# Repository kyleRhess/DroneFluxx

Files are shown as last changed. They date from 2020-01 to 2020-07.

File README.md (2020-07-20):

# DroneFluxx

## A custom quadcopter flight controller


### Firmware

The current firmware version is tailored for an STM32F4 microcontroller. This means that it is best-suited for the related hardware, and much of this firmware is very proprietary.
\
However, the lightweight [`PID module`](https://github.com/kyleRhess/DroneFluxx/blob/master/src/PID.c) built for this project could be useful in other applications.

### Hardware

Flight controller hardware is still in work, [`but has been made public`](https://github.com/kyleRhess/DroneFluxx/tree/master/Hardware) for those who are interested.

Alternate text

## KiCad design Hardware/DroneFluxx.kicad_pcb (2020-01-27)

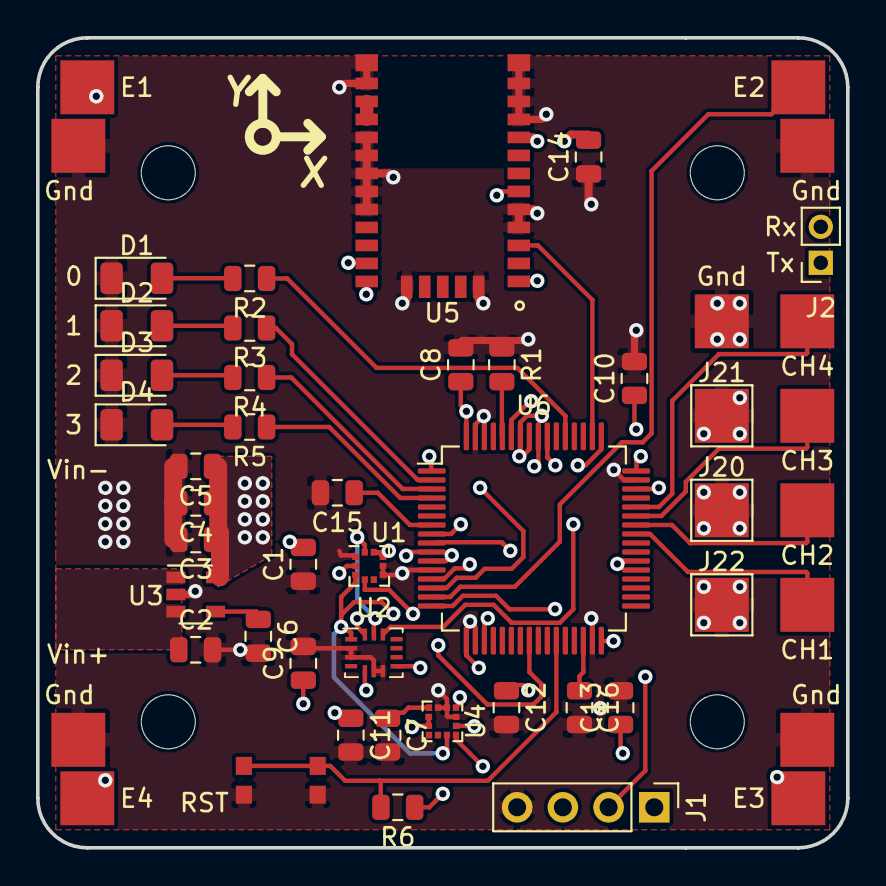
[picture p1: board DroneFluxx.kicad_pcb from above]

Board: 4 copper layers, 45.0 x 45.0 mm, 51 parts (0 on the bottom side), 40 nets.

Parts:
C1, C4, C7, C8, C10, C11, C12, C13, C15: 0.1uF; C_0805_2012Metric
C2, C9: 1uF; C_0805_2012Metric
C3, C16: 2.2uF; C_0805_2012Metric
C5, C6: 10nF; C_0805_2012Metric
C14: 4.7uF; C_0805_2012Metric
CH1, CH2, CH3, CH4: Conn_01x01_Female; Measurement_Point_Square-SMD-Pad_Big
D1, D2, D3, D4: LED; LED_1206_3216Metric
E1, E2, E3, E4: Conn_01x01_Female; Measurement_Point_Square-SMD-Pad_Big
Gnd: Conn_01x01_Female; Measurement_Point_Square-SMD-Pad_Big
Gnd#2, Gnd#3, Gnd#4, Gnd#5: Conn_01x01_Female; Measurement_Point_Square-SMD-Pad_Big
J1: Conn_01x04_Male; PinHeader_1x04_P2.54mm_Vertical
J2: Conn_01x02_Female; PinSocket_1x02_P2.00mm_Vertical
J20, J21, J22: Conn_01x01_Female; TestPoint_Pad_3.0x3.0mm
R1, R6: 10k; R_0805_2012Metric
R2, R3, R4, R5: 470; R_0805_2012Metric
RST: SW_Push; SW_SPST_KMR2
U1: BMP388; LGA-10_2x2mm_Pitch0.5mm
U2: LSM6DSM; Bosch_LGA-14_3x2.5mm_P0.5mm
U3: LP2985-3.3; SOT-23-5
U4: LIS3MDL; LGA-12_2x2mm_P0.5mm
U5: CAM-M8C-0; 31-SMD_Module
U6: STM32F410RBTx; LQFP-64_10x10mm_P0.5mm

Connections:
+3V3: C1.2, C3.1, C4.1, C5.1, C8.1, C9.1, C10.1, C11.1, C12.1, C13.1, C14.2, J1.3, R6.1, U1.1, U1.10, U2.5, U2.8, U3.5, U4.5, U4.6, U5.1, U5.9, U6.1, U6.13, U6.19, U6.32, U6.48, U6.64
+12V: C2.1, U3.1, U3.3
ESC1: E1.1, U6.14
ESC2: E2.1, U6.15
ESC3: E3.1, U6.16
ESC4: E4.1, U6.17
GND: C1.1, C2.2, C3.2, C4.2, C5.2, C6.2, C7.2, C8.2, C9.2, C10.2, C11.2, C12.2, C13.2, C14.1, C15.2, C16.2, D1.1, D2.1, D3.1, D4.1, Gnd.1, Gnd#2.1, Gnd#3.1, Gnd#4.1, Gnd#5.1, J1.4, J20.1, J21.1, J22.1, R1.1, RST.2, U1.3, U1.8, U1.9, U2.2, U2.3, U2.6, U2.7, U3.2, U4.2, U4.3, U4.12, U5.4, U5.5, U5.10, U5.11, U5.12, U5.13, U5.14, U5.15, U5.18, U5.19, U5.20, U5.21, U5.22, U5.27, U5.31, U6.12, U6.18, U6.31, U6.47, U6.63
LED_A: R2.1, U6.53
LED_B: R3.1, U6.2
LED_C: R4.1, U6.3
LED_D: R5.1, U6.4
unnamed: C6.1, U3.4
unnamed: C7.1, U4.4
unnamed: C15.1, U6.7
unnamed: C16.1, U6.30
unnamed: D1.2, R2.2
unnamed: D2.2, R3.2
unnamed: D3.2, R4.2
unnamed: D4.2, R5.2
unnamed: R1.2, U6.60
unnamed: U5.16, U5.17
RST_SW: R6.2, RST.1, U6.27
Rx_CH1: CH1.1, U6.41
Rx_CH2: CH2.1, U6.42
Rx_CH3: CH3.1, U6.43
Rx_CH4: CH4.1, U6.44
SPI1_CLK: U5.6, U6.55
SPI1_CS0: U5.3, U6.50
SPI1_MISO: U5.25, U6.56
SPI1_MOSI: U5.26, U6.57
SPI2_CLK: U1.2, U2.13, U4.1, U6.38
SPI2_CS0: U2.12, U6.8
SPI2_CS1: U4.10, U6.9
SPI2_CS2: U1.6, U6.24
SPI2_MISO: U1.5, U2.1, U4.9, U6.10
SPI2_MOSI: U1.4, U2.14, U4.11, U6.11
SWCLK: J1.2, U6.49
SWDIO: J1.1, U6.46
USART1_RX: J2.2, U6.59
USART1_TX: J2.1, U6.58

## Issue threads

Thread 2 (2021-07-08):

PID Windup Logic Bug

kyleRhess, 2021-07-08:
The integrator windup method in the PID library is incorrect and should be revisited.

Closed 2021-07-08.

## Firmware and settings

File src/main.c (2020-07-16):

/*
 * This file is part of the µOS++ distribution.
 *   (https://github.com/micro-os-plus)
 * Copyright (c) 2014 Liviu Ionescu.
 *
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
 * THE SOFTWARE IS PROVIDED "AS IS", WITHOUT WARRANTY OF ANY KIND,
 * EXPRESS OR IMPLIED, INCLUDING BUT NOT LIMITED TO THE WARRANTIES
 * OF MERCHANTABILITY, FITNESS FOR A PARTICULAR PURPOSE AND
 * NONINFRINGEMENT. IN NO EVENT SHALL THE AUTHORS OR COPYRIGHT
 * HOLDERS BE LIABLE FOR ANY CLAIM, DAMAGES OR OTHER LIABILITY,
 * WHETHER IN AN ACTION OF CONTRACT, TORT OR OTHERWISE, ARISING
 * FROM, OUT OF OR IN CONNECTION WITH THE SOFTWARE OR THE USE OR
 * OTHER DEALINGS IN THE SOFTWARE.
 */

/*
 *
____________________  _____________________________________  _________
___  ____/_  __ \_  |/ /__  ____/__  /____  _/_  ____/__  / / /__  __/
__  /_   _  / / /_    /__  /_   __  /  __  / _  / __ __  /_/ /__  /
_  __/   / /_/ /_    | _  __/   _  /____/ /  / /_/ / _  __  / _  /
/_/      \____/ /_/|_| /_/      /_____/___/  \____/  /_/ /_/  /_/
 *
 */

// ----------------------------------------------------------------------------
#include <stdio.h>
#include <stdlib.h>
#include <string.h>
#include <math.h>
#include "diag/Trace.h"
#include "cmsis_device.h"
#include "stm32f4xx.h"
#include "stm32f4xx_hal.h"
#include "stm32f4xx_hal_tim.h"
#include "System.h"

#define SQR(xxx) 			((xxx) * (xxx))

// ----------------------------------------------------------------------------
//
// Semihosting STM32F4 empty sample (trace via DEBUG).
//
// Trace support is enabled by adding the TRACE macro definition.
// By default the trace messages are forwarded to the DEBUG output,
// but can be rerouted to any device or completely suppressed, by
// changing the definitions required in system/src/diag/trace_impl.c
// (currently OS_USE_TRACE_ITM, OS_USE_TRACE_SEMIHOSTING_DEBUG/_STDOUT).
//

// ----- main() ---------------------------------------------------------------

// Sample pragmas to cope with warnings. Please note the related line at
// the end of this function, used to pop the compiler diagnostics status.
#pragma GCC diagnostic push
#pragma GCC diagnostic ignored "-Wunused-parameter"
#pragma GCC diagnostic ignored "-Wmissing-declarations"
#pragma GCC diagnostic ignored "-Wreturn-type"

static void setHighSystemClk(void);

int main(int argc, char* argv[])
{
	int status = HAL_OK;

	setHighSystemClk();
	status = InitializeSystem();

	RCC->AHB1ENR = RCC_AHB1ENR_GPIOCEN;
	RCC->AHB1ENR |= RCC_AHB1ENR_GPIOAEN;

	__HAL_RCC_GPIOB_CLK_ENABLE();

	GPIO_InitTypeDef gDataPin;
	gDataPin.Pin = GPIO_PIN_12 | GPIO_PIN_13 | GPIO_PIN_14 | GPIO_PIN_15;
	gDataPin.Mode = GPIO_MODE_OUTPUT_PP;
	gDataPin.Pull = GPIO_PULLUP;
	gDataPin.Speed = GPIO_SPEED_HIGH;
	HAL_GPIO_Init(GPIOC, &gDataPin);

	// Catch initialize failure
	while(status)
	{
		if(status & ERROR_IMU) 	aircraft_WriteLED(LED_A, 1);
		if(status & ERROR_BARO) aircraft_WriteLED(LED_B, 1);
		if(status & ERROR_GPS) 	aircraft_WriteLED(LED_C, 1);
		if(status & ERROR_MAG) 	aircraft_WriteLED(LED_D, 1);
	}

	SYSTEM_STATE = SYS_STATE_IDLE;
	AIRCRAFT_STATE = AIRCRAFT_STATE_ALIGNING;

	while (1)
	{
		// Start main loop
		RunSystem();
		RunSerial();
	}
	return 0;
}

/*
 * Need to re-initialize clocks to use HSI for PLL and
 * use PLL as the system clock with proper configs.
 *
 * This does not get set properly initially since after reset
 * needs to use HSI as system clock
 */
void setHighSystemClk(void)
{
	RCC_OscInitTypeDef RCC_OscInitStruct;

	// Use HSI and activate PLL with HSI as source.
	// This is tuned for NUCLEO-F411; update it for your board.
	RCC_OscInitStruct.OscillatorType = RCC_OSCILLATORTYPE_HSI;
	RCC_OscInitStruct.HSIState = RCC_HSI_ON;

	// 16 is the average calibration value, adjust for your own board.
	RCC_OscInitStruct.HSICalibrationValue = 16;
	RCC_OscInitStruct.PLL.PLLSource = RCC_PLLSOURCE_HSI;

	// This assumes the HSI_VALUE is a multiple of 1 MHz. If this is not
	// your case, you have to recompute these PLL constants.
	RCC_OscInitStruct.PLL.PLLM = (HSI_VALUE/1000000u);
	RCC_OscInitStruct.PLL.PLLN = 400; // for 100 MHz
	RCC_OscInitStruct.PLL.PLLP = RCC_PLLP_DIV4; /* 84 MHz, conservative */
	RCC_OscInitStruct.PLL.PLLQ = 7; /* To make USB work. */
	RCC_OscInitStruct.PLL.PLLState = RCC_PLL_ON;
	HAL_RCC_OscConfig(&RCC_OscInitStruct);

	RCC_ClkInitTypeDef RCC_ClkInitStruct;

	// Select PLL as system clock source and configure the HCLK, PCLK1 and PCLK2
	// clocks dividers
	RCC_ClkInitStruct.ClockType = (RCC_CLOCKTYPE_SYSCLK | RCC_CLOCKTYPE_HCLK
	  | RCC_CLOCKTYPE_PCLK1 | RCC_CLOCKTYPE_PCLK2);
	RCC_ClkInitStruct.SYSCLKSource = RCC_SYSCLKSOURCE_PLLCLK;

	// This is expected to work for most large cores.
	// Check and update it for your own configuration.
	RCC_ClkInitStruct.AHBCLKDivider = RCC_SYSCLK_DIV1;
	RCC_ClkInitStruct.APB1CLKDivider = RCC_HCLK_DIV1;
	RCC_ClkInitStruct.APB2CLKDivider = RCC_HCLK_DIV1;
	HAL_RCC_ClockConfig(&RCC_ClkInitStruct, FLASH_LATENCY_5);

	HAL_SYSTICK_Config(HAL_RCC_GetHCLKFreq()/1000);

	HAL_SYSTICK_CLKSourceConfig(SYSTICK_CLKSOURCE_HCLK);
}


#pragma GCC diagnostic pop

// ----------------------------------------------------------------------------

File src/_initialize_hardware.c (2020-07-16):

/*
 * This file is part of the µOS++ distribution.
 *   (https://github.com/micro-os-plus)
 * Copyright (c) 2014 Liviu Ionescu.
 *
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
 * THE SOFTWARE IS PROVIDED "AS IS", WITHOUT WARRANTY OF ANY KIND,
 * EXPRESS OR IMPLIED, INCLUDING BUT NOT LIMITED TO THE WARRANTIES
 * OF MERCHANTABILITY, FITNESS FOR A PARTICULAR PURPOSE AND
 * NONINFRINGEMENT. IN NO EVENT SHALL THE AUTHORS OR COPYRIGHT
 * HOLDERS BE LIABLE FOR ANY CLAIM, DAMAGES OR OTHER LIABILITY,
 * WHETHER IN AN ACTION OF CONTRACT, TORT OR OTHERWISE, ARISING
 * FROM, OUT OF OR IN CONNECTION WITH THE SOFTWARE OR THE USE OR
 * OTHER DEALINGS IN THE SOFTWARE.
 */

// ----------------------------------------------------------------------------

#include "stm32f4xx.h"
#include "stm32f4xx_hal.h"
#include "stm32f4xx_hal_cortex.h"

// ----------------------------------------------------------------------------

// The external clock frequency is specified as a preprocessor definition
// passed to the compiler via a command line option (see the 'C/C++ General' ->
// 'Paths and Symbols' -> the 'Symbols' tab, if you want to change it).
// The value selected during project creation was HSE_VALUE=8000000.
//
// The code to set the clock is at the end.
//
// Note1: The default clock settings assume that the HSE_VALUE is a multiple
// of 1MHz, and try to reach the maximum speed available for the
// board. It does NOT guarantee that the required USB clock of 48MHz is
// available. If you need this, please update the settings of PLL_M, PLL_N,
// PLL_P, PLL_Q to match your needs.
//
// Note2: The external memory controllers are not enabled. If needed, you
// have to define DATA_IN_ExtSRAM or DATA_IN_ExtSDRAM and to configure
// the memory banks in system/src/cmsis/system_stm32f4xx.c to match your needs.

// ----------------------------------------------------------------------------

// Forward declarations.

void
__initialize_hardware(void);

void
SystemClock_Config(void);

// ----------------------------------------------------------------------------

// This is the application hardware initialisation routine,
// redefined to add more inits.
//
// Called early from _start(), right after data & bss init, before
// constructors.
//
// After Reset the Cortex-M processor is in Thread mode,
// priority is Privileged, and the Stack is set to Main.
//
// Warning: The HAL requires the system timer, running at 1000 Hz
// and calling HAL_IncTick().

void
__initialize_hardware(void)
{
  // Initialise the HAL Library; it must be the first function
  // to be executed before the call of any HAL function.
  HAL_Init();

  // Enable HSE Oscillator and activate PLL with HSE as source
  SystemClock_Config();

  // Call the CSMSIS system clock routine to store the clock frequency
  // in the SystemCoreClock global RAM location.
  SystemCoreClockUpdate();
}

// Disable when using RTOSes, since they have their own handler.
#if 0

// This is a sample SysTick handler, use it if you need HAL timings.
void __attribute__ ((section(".after_vectors")))
SysTick_Handler(void)
{
#if defined(USE_HAL_DRIVER)
	HAL_IncTick();
#endif
}

#endif

// ----------------------------------------------------------------------------

/**
 * @brief  System Clock Configuration
 * @param  None
 * @retval None
 */
void
__attribute__((weak))
SystemClock_Config(void)
{
  // Enable Power Control clock
  __PWR_CLK_ENABLE();

  // The voltage scaling allows optimizing the power consumption when the
  // device is clocked below the maximum system frequency, to update the
  // voltage scaling value regarding system frequency refer to product
  // datasheet.
  __HAL_PWR_VOLTAGESCALING_CONFIG(PWR_REGULATOR_VOLTAGE_SCALE1);

#warning "Please check if the SystemClock_Config() settings match your board!"
  // Comment out the warning after checking and updating.

  RCC_OscInitTypeDef RCC_OscInitStruct;

#if defined(HSE_VALUE) && (HSE_VALUE != 0)
  // Enable HSE Oscillator and activate PLL with HSE as source.
  // This is tuned for STM32F4-DISCOVERY; update it for your board.
  RCC_OscInitStruct.OscillatorType = RCC_OSCILLATORTYPE_HSE;
  RCC_OscInitStruct.HSEState = RCC_HSE_ON;
  RCC_OscInitStruct.PLL.PLLSource = RCC_PLLSOURCE_HSE;
  // This assumes the HSE_VALUE is a multiple of 1 MHz. If this is not
  // your case, you have to recompute these PLL constants.
  RCC_OscInitStruct.PLL.PLLM = (HSE_VALUE/1000000u);
#else
  // Use HSI and activate PLL with HSI as source.
  // This is tuned for NUCLEO-F411; update it for your board.
  RCC_OscInitStruct.OscillatorType = RCC_OSCILLATORTYPE_HSI;
  RCC_OscInitStruct.HSIState = RCC_HSI_ON;
  // 16 is the average calibration value, adjust for your own board.
  RCC_OscInitStruct.HSICalibrationValue = 16;
  RCC_OscInitStruct.PLL.PLLSource = RCC_PLLSOURCE_HSI;
  // This assumes the HSI_VALUE is a multiple of 1 MHz. If this is not
  // your case, you have to recompute these PLL constants.
  RCC_OscInitStruct.PLL.PLLM = (HSI_VALUE/1000000u);
#endif

  RCC_OscInitStruct.PLL.PLLN = 400; // for 100 MHz
#if defined(STM32F401xC) || defined(STM32F401xE) || defined(STM32F411xE)
  RCC_OscInitStruct.PLL.PLLP = RCC_PLLP_DIV4; /* 84 MHz */
#elif defined(STM32F427xx) || defined(STM32F437xx) || defined(STM32F429xx) || defined(STM32F439xx)
  RCC_OscInitStruct.PLL.PLLP = RCC_PLLP_DIV2; /* 168 MHz */
#elif defined(STM32F405xx) || defined(STM32F415xx) || defined(STM32F407xx) || defined(STM32F417xx)
  RCC_OscInitStruct.PLL.PLLP = RCC_PLLP_DIV2; /* 168 MHz */
#elif defined(STM32F446xx)
  RCC_OscInitStruct.PLL.PLLP = RCC_PLLP_DIV2; /* 168 MHz */
#else
  RCC_OscInitStruct.PLL.PLLP = RCC_PLLP_DIV4; /* 84 MHz, conservative */
#endif
  RCC_OscInitStruct.PLL.PLLQ = 7; /* To make USB work. */
  RCC_OscInitStruct.PLL.PLLState = RCC_PLL_ON;
  HAL_RCC_OscConfig(&RCC_OscInitStruct);

  RCC_ClkInitTypeDef RCC_ClkInitStruct;
  // Select PLL as system clock source and configure the HCLK, PCLK1 and PCLK2
  // clocks dividers
  RCC_ClkInitStruct.ClockType = (RCC_CLOCKTYPE_SYSCLK | RCC_CLOCKTYPE_HCLK
		  	  	  	  	  	  | RCC_CLOCKTYPE_PCLK1 | RCC_CLOCKTYPE_PCLK2);
  RCC_ClkInitStruct.SYSCLKSource = RCC_SYSCLKSOURCE_PLLCLK;
#if defined(STM32F401xC) || defined(STM32F401xE) || defined(STM32F411xE)
  RCC_ClkInitStruct.AHBCLKDivider = RCC_SYSCLK_DIV1;
  RCC_ClkInitStruct.APB1CLKDivider = RCC_HCLK_DIV2;
  RCC_ClkInitStruct.APB2CLKDivider = RCC_HCLK_DIV1;
  HAL_RCC_ClockConfig(&RCC_ClkInitStruct, FLASH_LATENCY_2);
#else
  // This is expected to work for most large cores.
  // Check and update it for your own configuration.
  RCC_ClkInitStruct.AHBCLKDivider = RCC_SYSCLK_DIV1;
  RCC_ClkInitStruct.APB1CLKDivider = RCC_HCLK_DIV4;
  RCC_ClkInitStruct.APB2CLKDivider = RCC_HCLK_DIV2;
  HAL_RCC_ClockConfig(&RCC_ClkInitStruct, FLASH_LATENCY_5);
#endif

  HAL_SYSTICK_Config(HAL_RCC_GetHCLKFreq()/1000);

  HAL_SYSTICK_CLKSourceConfig(SYSTICK_CLKSOURCE_HCLK);
}

// ----------------------------------------------------------------------------

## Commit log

2020-01-25 Added hardware files.
    [DroneFluxx.kicad_pcb, DroneFluxx.sch]
2020-01-27 Updated hardware to use latest library references.
    [DroneFluxx.kicad_pcb, DroneFluxx.sch]
2020-02-11 Unused code cleanup.
    -Extract all Mag functions into Mag.c since not using Mag for now.
    -Extract all GPS functions into GPS.c since not using GPS for now.
    -Get rid of "angle control" in Aircraft.c
    -Moved processing of IMU and baro data into their respective .C files
    -Perform general code cleanup and commenting.
    [DroneFluxx.sch]
2020-02-14 Simplified disarming procedure.
    -Moved LED flashing to Data.c ISR for consistency.
    -Removed some unsed variables
    -Decreased disarming time
    -General code clean-up
2020-02-19 Fixed UART receiver
    Eliminated use of "HAL_UART_Receive_IT" and instead get UART data on a single byte interrupt. This allows receiving any number of bytes.
    [Serial.c, System.c]
2020-07-16 Code cleanup.
    Removed some redundancy and fixed some formatting.
    [Aircraft.c, Aircraft.h, Baro.c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]
2021-07-08 Replaced arbitrary value. Fixes #1
    [Aircraft.c]
2021-07-08 Updated PID library to use a more robust integrator windup guard. Fixes #2
